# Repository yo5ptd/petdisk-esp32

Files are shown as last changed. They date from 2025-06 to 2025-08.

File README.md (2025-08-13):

# petdisk-esp32
CBM PETDISK based on Esp32 and MicroSD

## Introduction
My fourth PCB design, first (mostly) SMD one to test how ordering assembled PCB from JLCPCB works. Motivation for this was that it's a bit of a pain to order @bitfixer 's Petdisk Max V2 Esp32 from the US, and I've found no alternatives in the EU. 

## Hardware documentation

As per bitfixer's Petdisk V2 Max https://github.com/bitfixer/petdisk-max . Ports as per https://github.com/svenpetersen1965/PET-IEEE-488-Extension .

I've only changed the SD slot to Hanbo Electric TS-013 as this was available at JLCPCB.

### Schematic and PCB layout

[Schematic](CBM-Petdisk-Schematic.pdf)

[PCB Layout](CBM-Petdisk-Board.pdf)

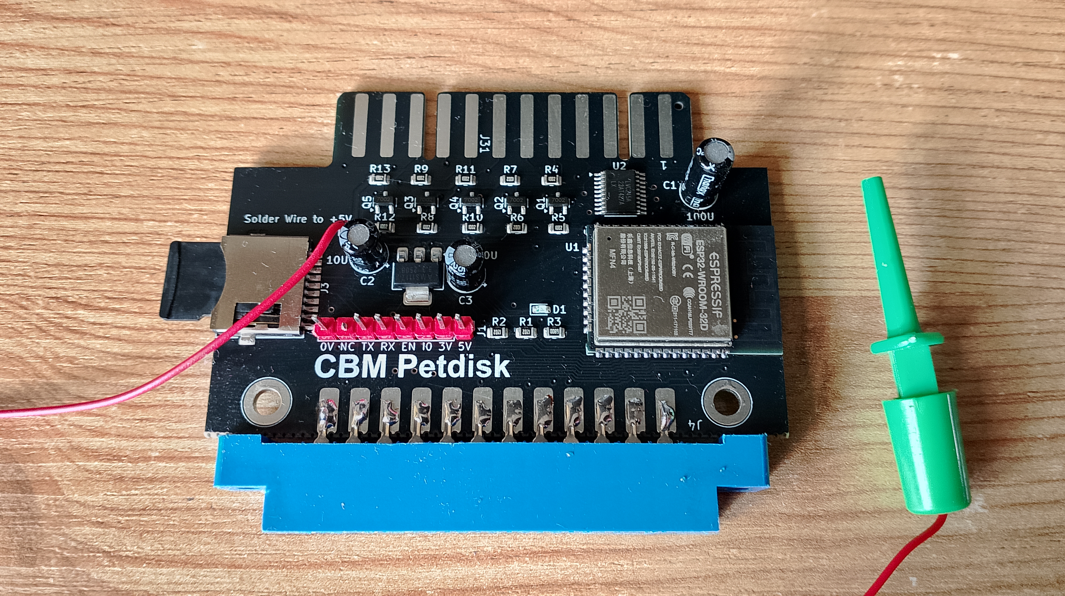
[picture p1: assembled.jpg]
Assembled


[Front](petdisk%20esp32.jpg)

[Back](petdisk%20esp32-back.jpg)

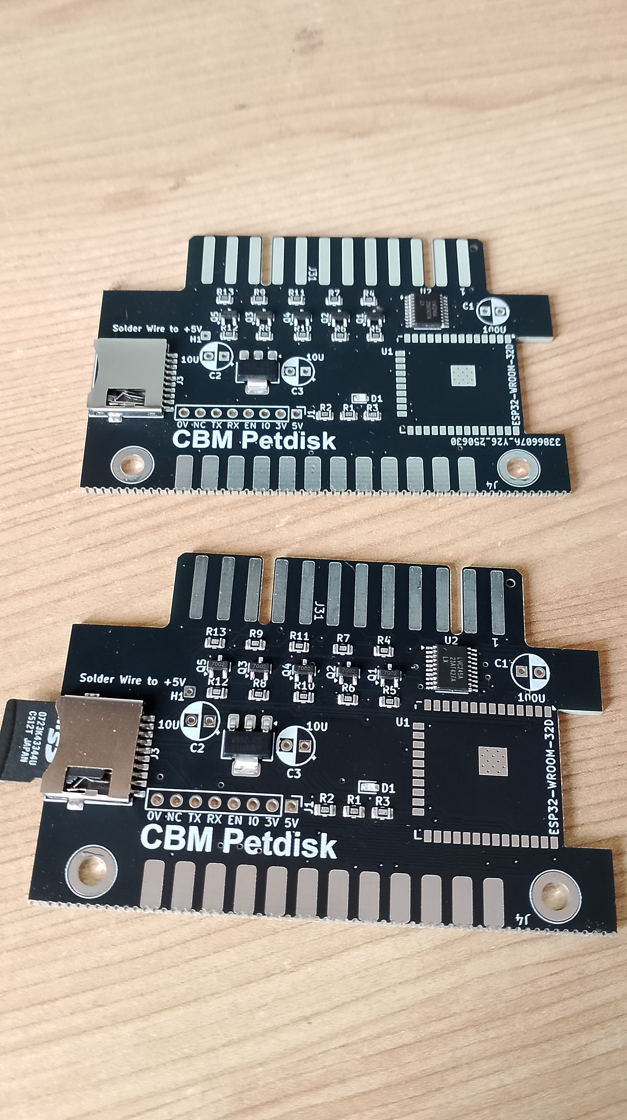
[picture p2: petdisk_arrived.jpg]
Received


## Panelization and odering from JLCPCB

Panelized with Kikit addon with hand-breakable "mousebytes", it still fits the 100x100 mm JLCPCB limit (Kikit.json settings included, details in https://github.com/yaqwsx/KiKit). 

The idea is to order the placement for the cheap SMD components, and only solder 3 electrolytic capacitors, the ESP32 module and a "805 Strip Connector 3.96mm Pitch 12 Pin" connector from Aliexpress. Cost per board from JLPCB thus is around 3.3$ when ordered in batches of 5 (10 boards in total, coupons used, shipping and taxes included) With connector, capacitors, esp32 should not get over 8.5$ per board, but probably more as I don't plan to order 10 of these.

You need the:
[Gerbers](gerbers.2xpetdisk-esp32.zip)

[BOM](BOM_JLCSMT.xlsx)

[CPL](JLCSMT_CPL.xlsx)

Disregards the duplicate message, also allow auto placement alignment.

## Programming

note that the programming port pinout is different from the original.

First board was fully assembled and tested on 29.07.2025. Note that I managed to get it working with the original Petdisk max v2.1 firmware with a 32GB card. 512mb, 1gb and 128gb cards were not recognized.

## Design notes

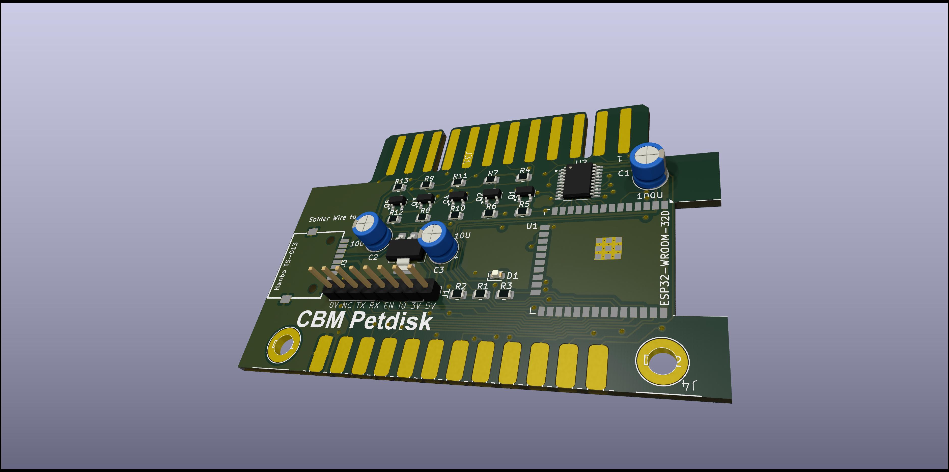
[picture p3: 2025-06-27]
petdisk esp32.jpg

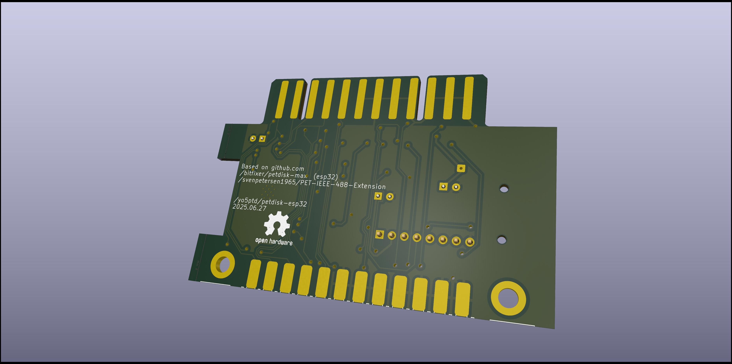
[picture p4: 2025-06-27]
petdisk esp32-back.jpg

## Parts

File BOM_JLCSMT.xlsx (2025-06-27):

Comment | Designator | Footprint | JLCPCB Part #（optional）
10K | R7,R8,R11,R12,R4,R9,R10,R5,R6,R13 | R_0805_2012Metric | C17414
BSS138K | Q1,Q3,Q2,Q5,Q4 | SOT-23 | C8545
Micro_SD_Card_Det2 | J3 | TF-SMD_TF-013 | C961683
LED | D1 | LED_0603_1608Metric | C2286
AMS1117-3.3 | U3 | SOT-223-3_TabPin2 | C6186
12K | R1,R2 | R_0805_2012Metric | C17444
1K | R3 | R_0805_2012Metric | C17798
SN74LVC245APW | U2 | TSSOP-20_4.4x6.5mm_P0.65mm | C41361216
ESP32-WROOM-32D | U1 | ESP32-WROOM-32D | C473012

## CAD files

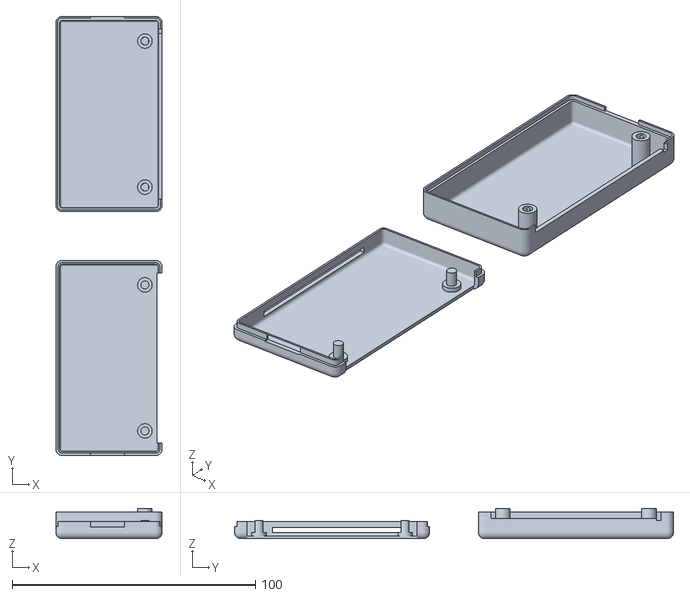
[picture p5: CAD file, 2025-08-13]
Yapp_petdisk_cbm.stl
43.7 x 180.4 x 12.4

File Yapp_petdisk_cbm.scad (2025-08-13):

/*
***************************************************************************  
**  Yet Another Parameterised Projectbox generator
**
*/

Version="v3.3.5 (2025-02-24)";

/*
**
**  Copyright (c) 2021, 2022, 2023, 2024, 2025 Willem Aandewiel
**
**  With help from:
**   - Keith Hadley (parameterized label depth)
**   - Oliver Grafe (connectorsPCB)
**   - Juan Jose Chong (dynamic standoff flange)
**   - Dan Drum (cleanup code)
**   - Dave Rosenhauer (fillets and a lot more)
**
**
**  for many or complex cutouts you might need to adjust
**  the number of elements:
**
**      Preferences->Advanced->Turn off rendering at 250000 elements
**                                                  ^^^^^^
**
**  TERMS OF USE: MIT License. See base offile.
***************************************************************************      
*/

// If set to true will generate the sample box at every save
debug = true;
printMessages = debug;

//---------------------------------------------------------
// This design is parameterized based on the size of a PCB.
//---------------------------------------------------------
// Note: length/lengte refers to X axis, 
//       width/breedte to Y, 
//       height/hoogte to Z

/*
      padding-back|<------pcb length --->|<padding-front
                            RIGHT
        0    X-axis ---> 
        +----------------------------------------+   ---
        |                                        |    ^
        |                                        |   padding-right 
      Y |                                        |    v
      | |    -5,y +----------------------+       |   ---              
 B    a |         | 0,y              x,y |       |     ^              F
 A    x |         |                      |       |     |              R
 C    i |         |                      |       |     | pcb width    O
 K    s |         |                      |       |     |              N
        |         | 0,0              x,0 |       |     v              T
      ^ |    -5,0 +----------------------+       |   ---
      | |                                        |    padding-left
      0 +----------------------------------------+   ---
        0    X-as --->
                          LEFT
*/

//-- which part(s) do you want to print?
printBaseShell        = true;
printLidShell         = true;
printSwitchExtenders  = true;
printDisplayClips     = true;
shiftLid              = 10;  // Set the distance between the lid and base when rendered or previewed side by side
                            
//-- padding between pcb and inside wall
paddingFront        = 1;
paddingBack         = 1;
paddingRight        = 1;
paddingLeft         = 1;

// ********************************************************************
// The Following will be used as the first element in the pbc array

//Defined here so you can define the "Main" PCB using these if wanted
pcbLength           = 38.5; // front to back (X axis)
pcbWidth            = 75; // side to side (Y axis)
pcbThickness        = 1.6;
standoffHeight      = 1.5;  //-- How much the PCB needs to be raised from the base to leave room for solderings 
standoffDiameter    = 6;
standoffPinDiameter = 3.3;
standoffHoleSlack   = 0.4;

//===================================================================
// *** PCBs ***
// Printed Circuit Boards
//-------------------------------------------------------------------
//  Default origin =  yappCoordPCB : yappCoordBoxInside[0,0,0]
//
//  Parameters:
//   Required:
//    p(0) = name
//    p(1) = length
//    p(2) = width
//    p(3) = posx
//    p(4) = posy
//    p(5) = Thickness
//    p(6) = standoff_Height = Height to bottom of PCB from the inside of the base
//             negative measures from inside of the lid to the top of the PCB
//    p(7) = standoff_Diameter
//    p(8) = standoff_PinDiameter
//   Optional:
//    p(9) = standoff_HoleSlack (default to 0.4)

//The following can be used to get PCB values. If "PCB Name" is omitted then "Main" is used
//  pcbLength           --> pcbLength("PCB Name")
//  pcbWidth            --> pcbWidth("PCB Name")
//  pcbThickness        --> pcbThickness("PCB Name") 
//  standoffHeight      --> standoffHeight("PCB Name") 
//  standoffDiameter    --> standoffDiameter("PCB Name") 
//  standoffPinDiameter --> standoffPinDiameter("PCB Name") 
//  standoffHoleSlack   --> standoffHoleSlack("PCB Name") 

pcb = 
[
  //-- Default Main PCB - DO NOT REMOVE the "Main" line.
  ["Main",              pcbLength,pcbWidth,    0,0,    pcbThickness,  standoffHeight, standoffDiameter, standoffPinDiameter, standoffHoleSlack]
];

//-------------------------------------------------------------------

//-- Edit these parameters for your own box dimensions
wallThickness       = 1.6;
basePlaneThickness  = 1.0;
lidPlaneThickness   = 1.0;

//-- Total height of box = lidPlaneThickness 
//                       + lidWallHeight 
//                       + baseWallHeight 
//                       + basePlaneThickness
//-- space between pcb and lidPlane :=
//--      (bottonWallHeight+lidWallHeight) - (standoff_Height+pcb_Thickness)
baseWallHeight      = 6;
lidWallHeight       = 8.5;

//-- ridge where base and lid off box can overlap
//-- Make sure this isn't less than lidWallHeight 
//     or 1.8x wallThickness if using snaps
ridgeHeight         = 2.0;
ridgeSlack          = 0.3;

//-- Radius of the shell corners
roundRadius         = wallThickness + 1;

// Box Types are 0-5 with 0 as the default
// 0 = All edges rounded with radius (roundRadius) above
// 1 = All edges square
// 2 = All edges chamfered by (roundRadius) above 
// 3 = Square top and bottom edges (the ones that touch the build plate) and rounded vertical edges
// 4 = Square top and bottom edges (the ones that touch the build plate) and chamfered vertical edges
// 5 = Chamfered top and bottom edges (the ones that touch the build plate) and rounded vertical edges
boxType = 0; // Default type 0


//---------------------------
//--     MISC Options     --
//---------------------------

//-- Cone aperture in degrees for countersunk-head screws
countersinkAngle = 90;          //-- metric: 90

// Set the layer height of your printer
printerLayerHeight  = 0.2;

// Set the ratio between the wall thickness and the ridge height. 
//    Recommended to be left at 1.8 but for strong snaps.
wallToRidgeRatio = 1.8;

//---------------------------
//--     C O N T R O L     --
//---------------------------
// -- Render --
renderQuality             = 8;          //-> from 1 to 32, Default = 8

// --Preview --
previewQuality            = 5;          //-> from 1 to 32, Default = 5
showSideBySide            = true;       //-> Default = true
onLidGap                  = 0;  // tip don't override to animate the lid opening
//onLidGap                  = ((ridgeHeight) - (ridgeHeight * abs(($t-0.5)*2)))*2;  // tip don't override to animate the lid opening/closing
colorLid                  = "YellowGreen";   
alphaLid                  = 1;
colorBase                 = "BurlyWood";
alphaBase                 = 1;
hideLidWalls              = false;      //-> Remove the walls from the lid : only if preview and showSideBySide=true 
hideBaseWalls             = false;      //-> Remove the walls from the base : only if preview and showSideBySide=true  
showOrientation           = true;       //-> Show the Front/Back/Left/Right labels : only in preview
showPCB                   = false;      //-> Show the PCB in red : only in preview 
showSwitches              = false;      //-> Show the switches (for pushbuttons) : only in preview 
showButtonsDepressed      = false;      //-> Should the buttons in the Lid On view be in the pressed position
showOriginCoordBox        = false;      //-> Shows red bars representing the origin for yappCoordBox : only in preview 
showOriginCoordBoxInside  = false;      //-> Shows blue bars representing the origin for yappCoordBoxInside : only in preview 
showOriginCoordPCB        = false;      //-> Shows blue bars representing the origin for yappCoordBoxInside : only in preview 
showMarkersPCB            = false;      //-> Shows black bars corners of the PCB : only in preview 
showMarkersCenter         = false;      //-> Shows magenta bars along the centers of all faces  
inspectX                  = 0;          //-> 0=none (>0 from Back)
inspectY                  = 0;          //-> 0=none (>0 from Right)
inspectZ                  = 0;          //-> 0=none (>0 from Bottom)
inspectXfromBack          = true;       //-> View from the inspection cut foreward
inspectYfromLeft          = true;       //-> View from the inspection cut to the right
inspectZfromBottom        = true;       //-> View from the inspection cut up
//---------------------------
//--     C O N T R O L     --
//---------------------------

// ******************************
//  REMOVE BELOW FROM TEMPLATE

// Set the glogal for the quality
facetCount = $preview ? previewQuality*4 : renderQuality*4;
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

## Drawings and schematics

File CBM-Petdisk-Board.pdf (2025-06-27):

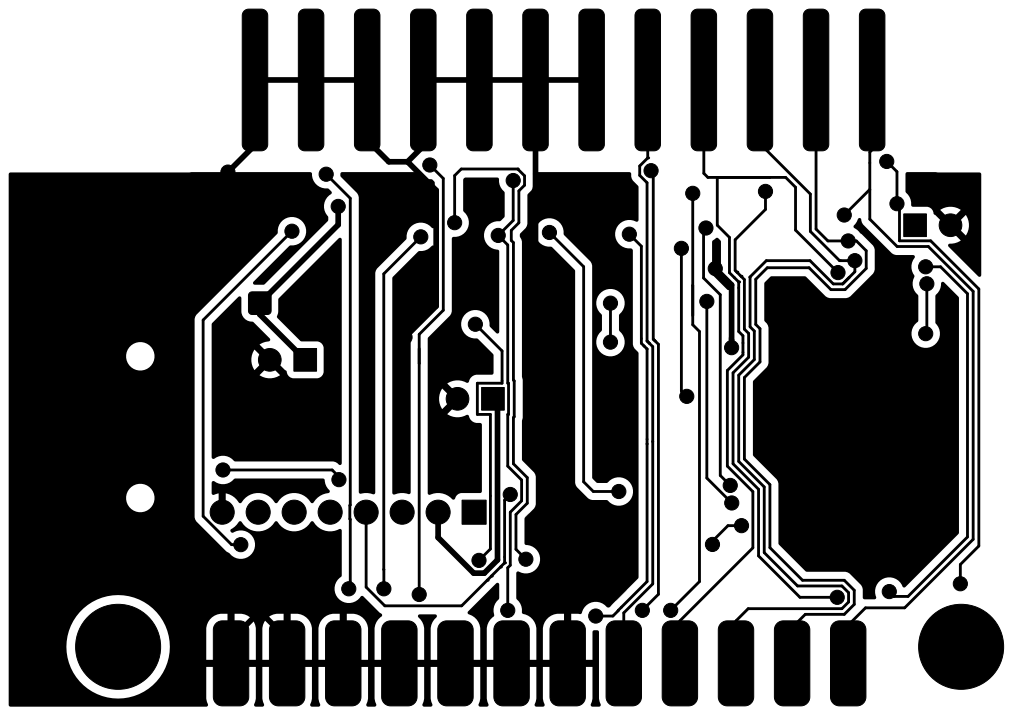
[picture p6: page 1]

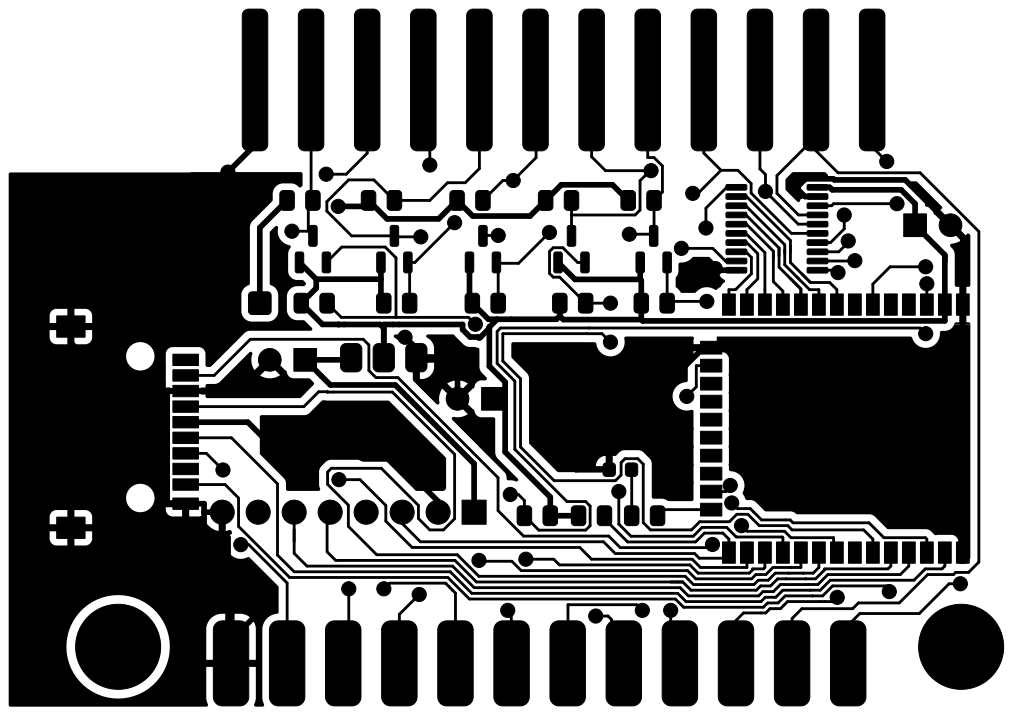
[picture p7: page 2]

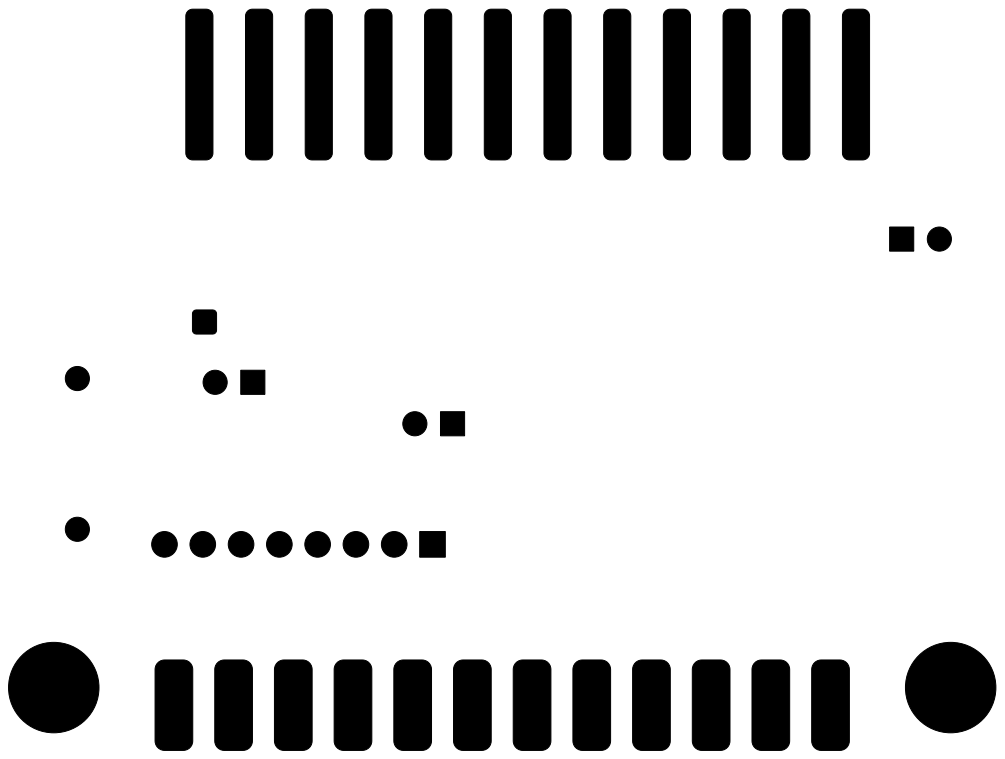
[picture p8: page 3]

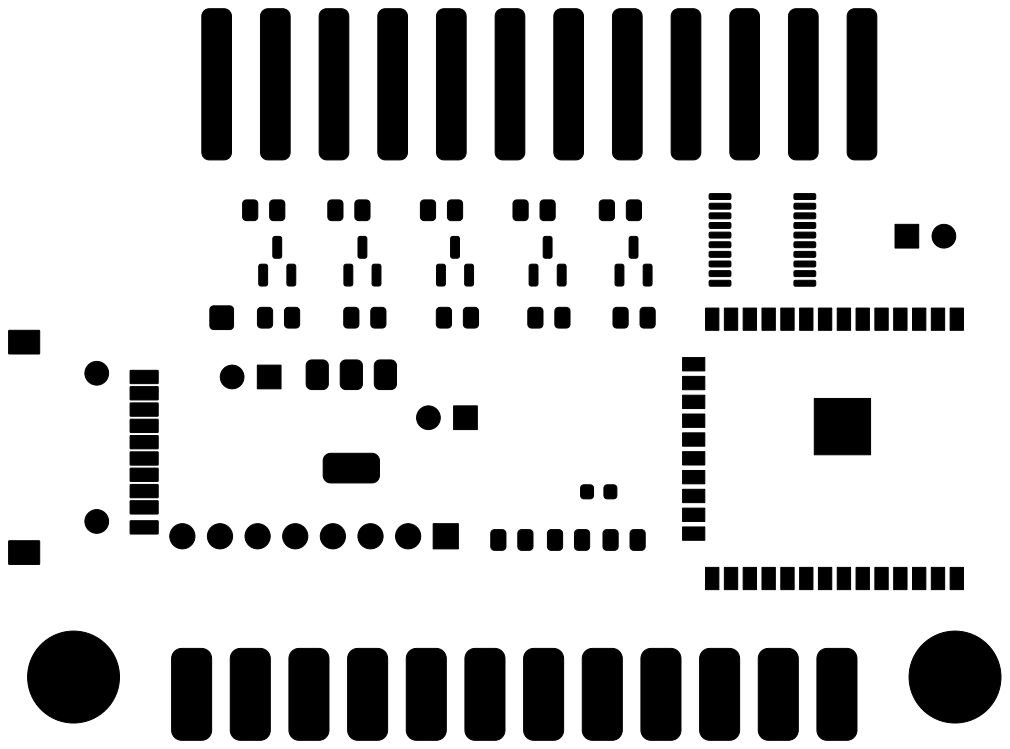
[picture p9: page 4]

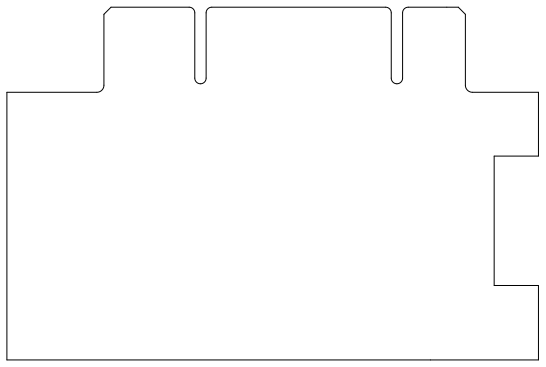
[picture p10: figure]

U2 10K R13 | BOHR3,5 Conn_01x08 | J1 BOHR3,5

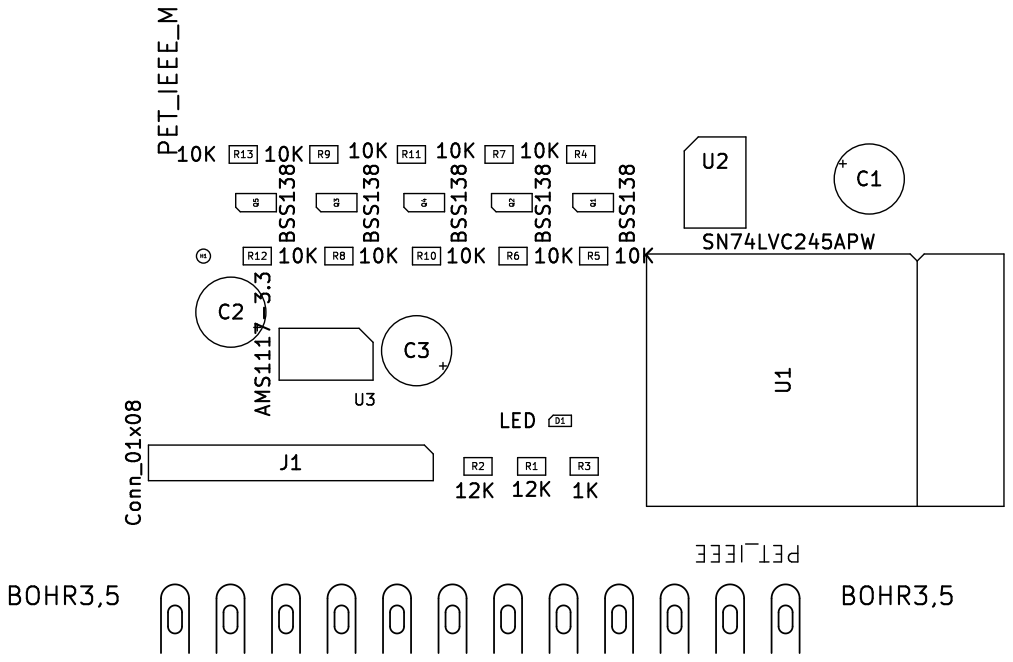
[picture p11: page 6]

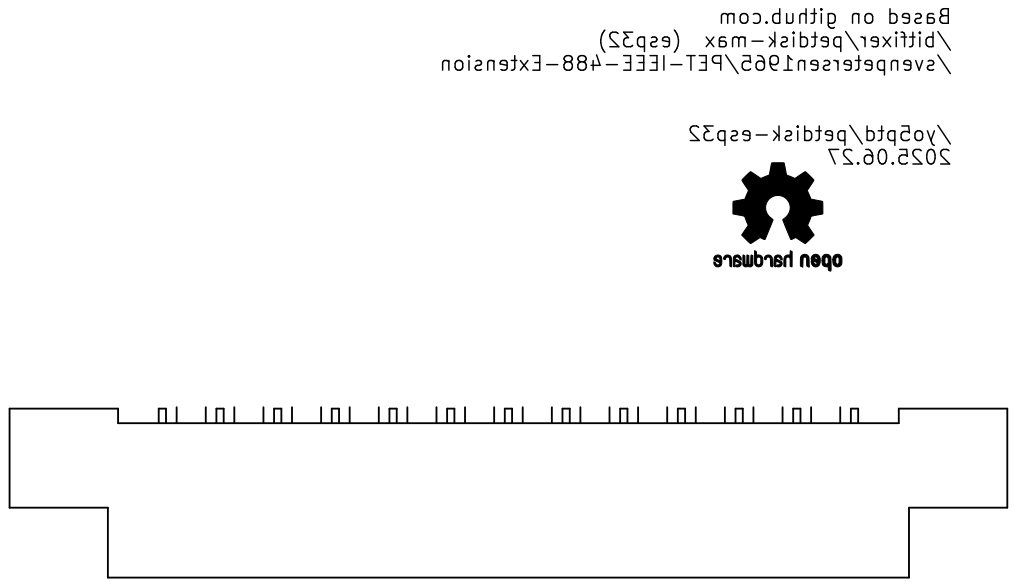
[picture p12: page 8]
/yo5ptd/petdisk-esp32 2025.06.27

github.com on Based

/svenpetersen1965/PET-IEEE-488-Extension

(esp32) /bitfixer/petdisk-max

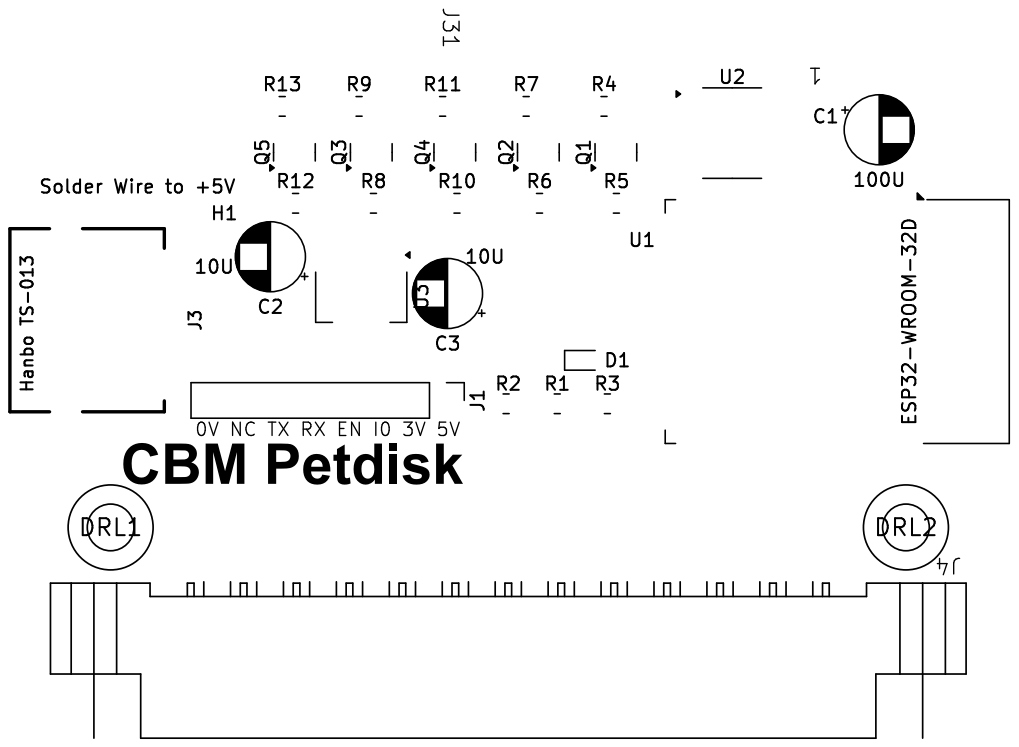
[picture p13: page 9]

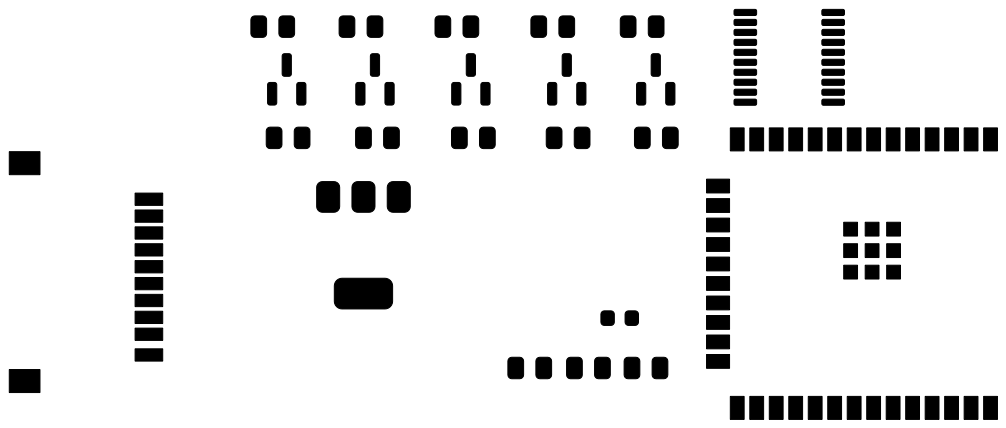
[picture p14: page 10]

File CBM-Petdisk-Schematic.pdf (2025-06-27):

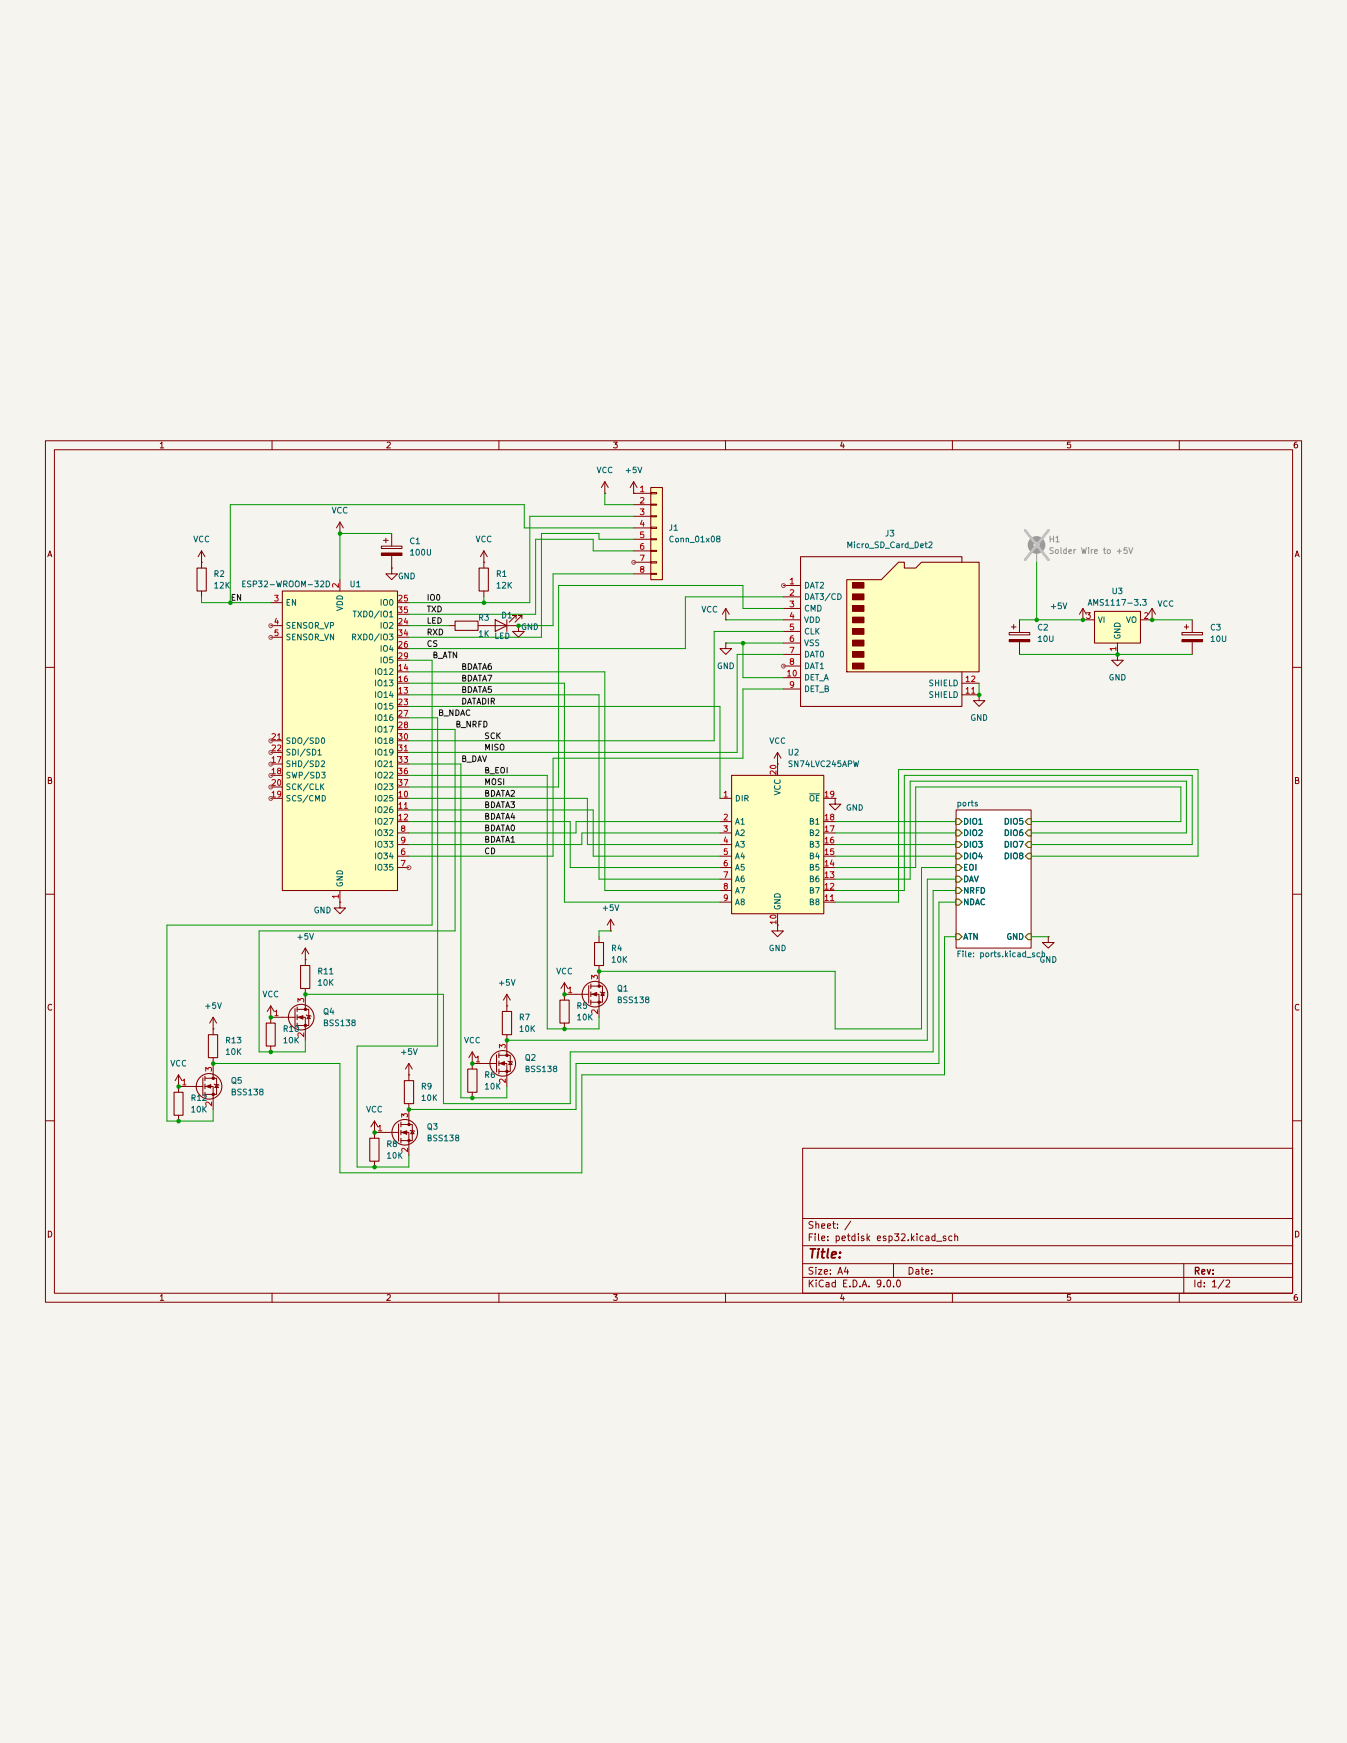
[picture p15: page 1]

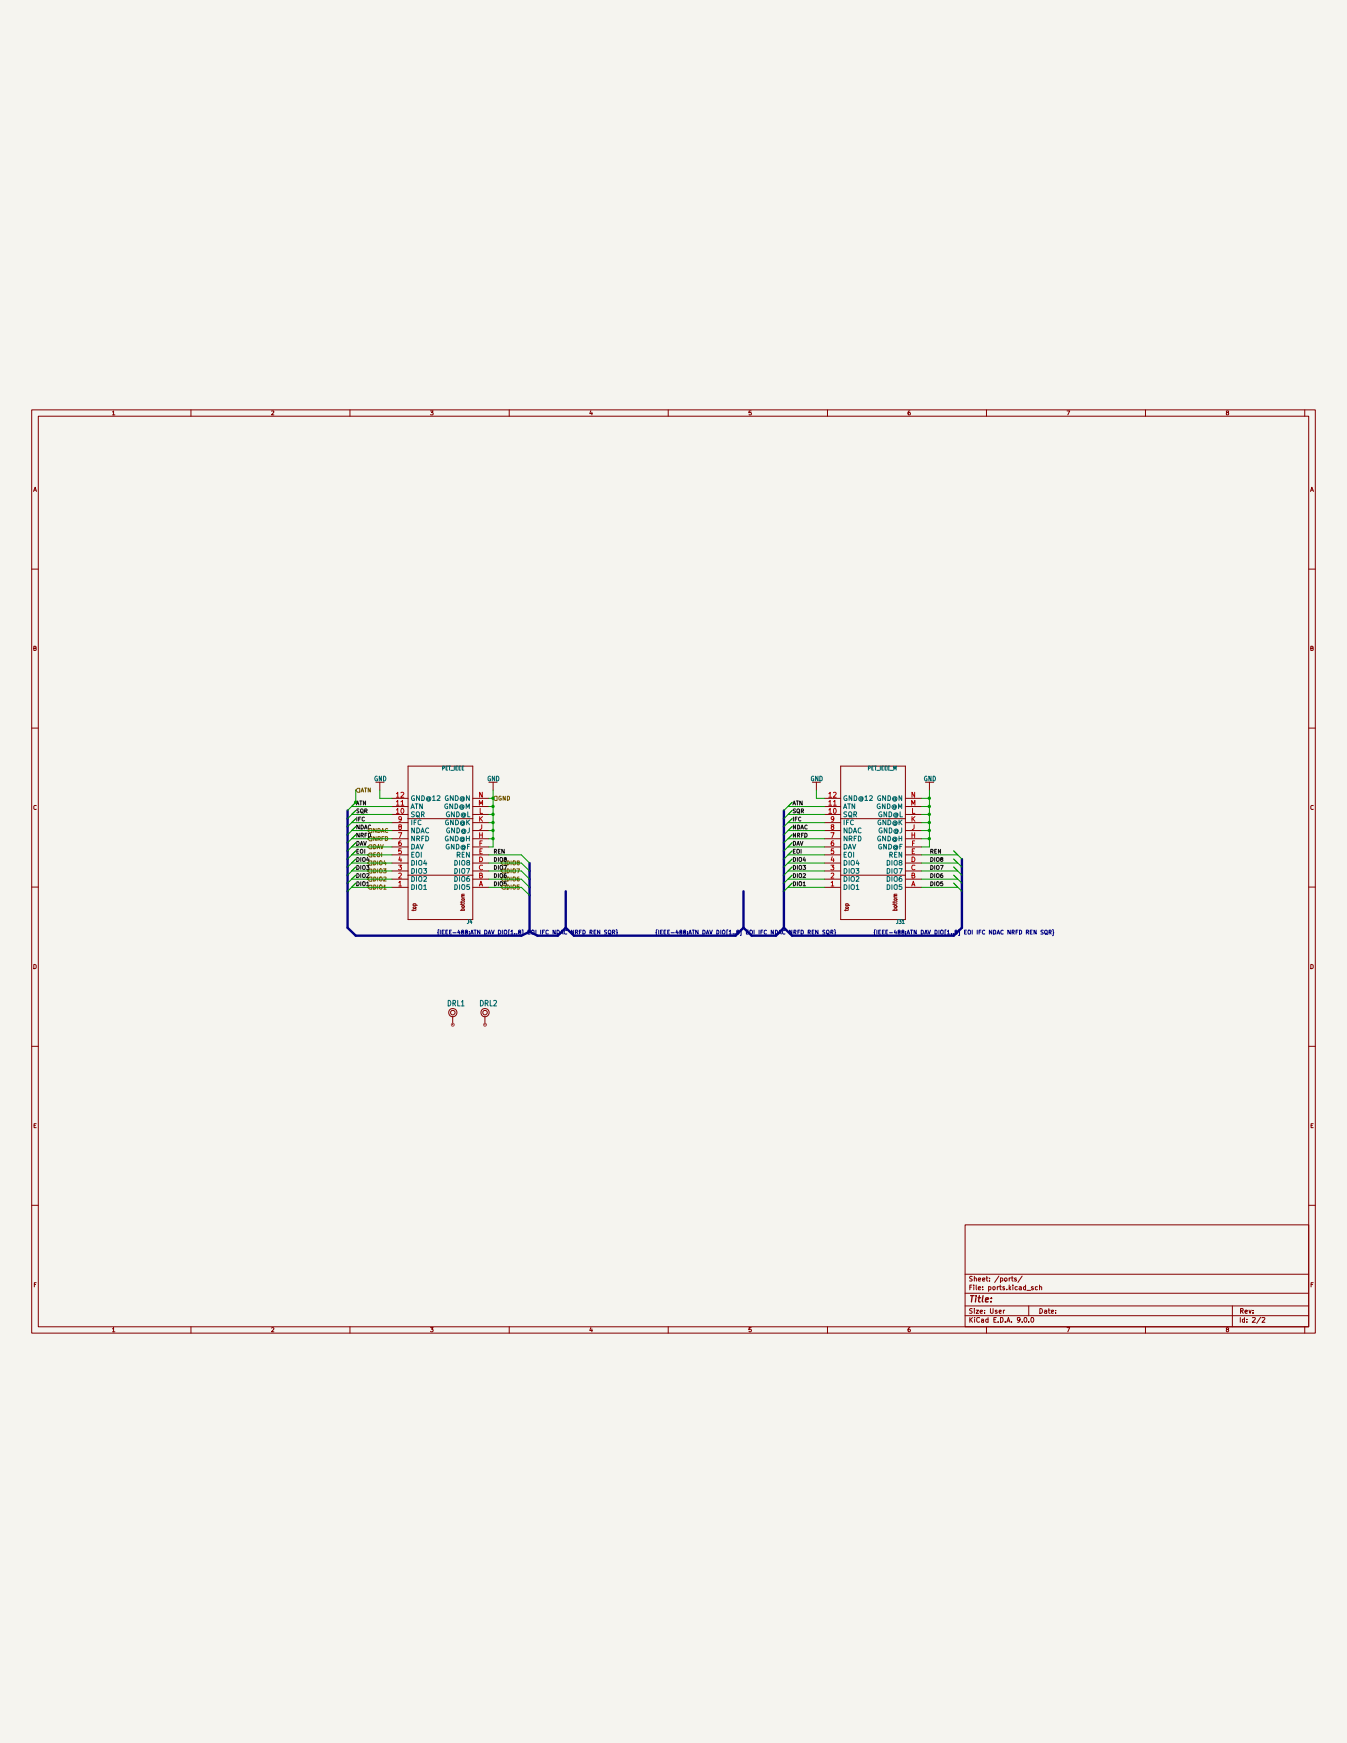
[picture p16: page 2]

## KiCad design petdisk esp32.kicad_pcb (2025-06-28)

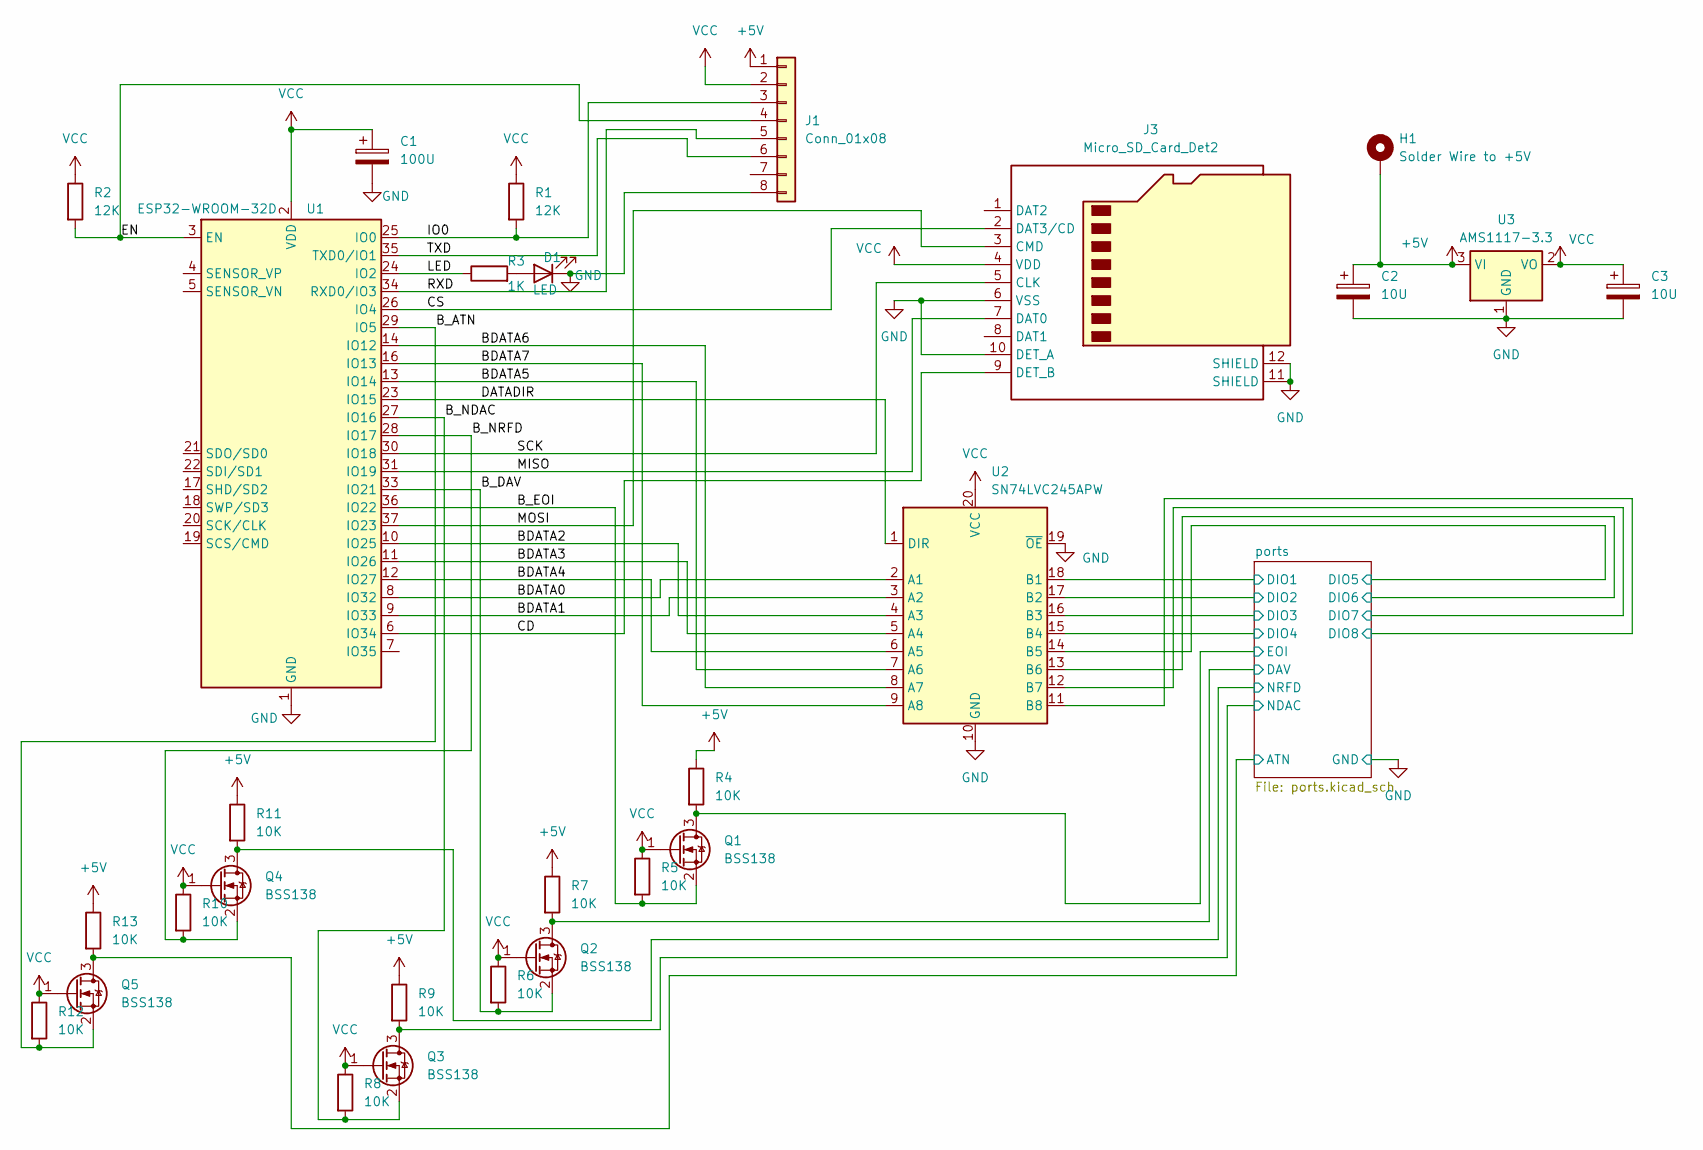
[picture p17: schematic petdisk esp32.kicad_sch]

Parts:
C1: 100U; CP_Radial_D5.0mm_P2.50mm
C2, C3: 10U; CP_Radial_D5.0mm_P2.50mm
D1: LED; LED_0603_1608Metric
H1: Solder Wire to +5V; SolderWire-0.1sqmm_1x01_D0.4mm_OD1mm
J1: Conn_01x08; PinHeader_1x08_P2.54mm_Vertical
J3: Micro_SD_Card_Det2; TF-SMD_TF-013
Q1, Q2, Q3, Q4, Q5: BSS138; SOT-23
R1, R2: 12K; R_0805_2012Metric
R3: 1K; R_0805_2012Metric
R4, R5, R6, R7, R8, R9, R10, R11, R12, R13: 10K; R_0805_2012Metric
U1: ESP32-WROOM-32D
U2: SN74LVC245APW; TSSOP-20_4.4x6.5mm_P0.65mm
U3: AMS1117-3.3; SOT-223-3_TabPin2

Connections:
+5V: C2.1, H1.1, J1.1, R4.1, R7.1, R9.1, R11.1, R13.1, U3.3 (VI)
/BDATA0: U1.8 (IO32), U2.2 (A1)
/BDATA1: U1.9 (IO33), U2.3 (A2)
/BDATA2: U1.10 (IO25), U2.4 (A3)
/BDATA3: U1.11 (IO26), U2.5 (A4)
/BDATA4: U1.12 (IO27), U2.6 (A5)
/BDATA5: U1.13 (IO14), U2.7 (A6)
/BDATA6: U1.14 (IO12), U2.8 (A7)
/BDATA7: U1.16 (IO13), U2.9 (A8)
/B_ATN: Q5.2 (S), R12.2, U1.29 (IO5)
/B_DAV: Q2.2 (S), R6.2, U1.33 (IO21)
/B_EOI: Q1.2 (S), R5.2, U1.36 (IO22)
/B_NDAC: Q3.2 (S), R8.2, U1.27 (IO16)
/B_NRFD: Q4.2 (S), R10.2, U1.28 (IO17)
/CD: J3.9 (DET_B), U1.6 (IO34)
/CS: J3.2 (DAT3/CD), U1.26 (IO4)
/DATADIR: U1.23 (IO15), U2.1 (DIR)
/EN: J1.4, R2.2, U1.3 (EN)
/IO0: J1.3, R1.2, U1.25 (IO0)
/LED: R3.1, U1.24 (IO2)
/MISO: J3.7 (DAT0), U1.31 (IO19)
/MOSI: J3.3 (CMD), U1.37 (IO23)
/RXD: J1.5, U1.34 (RXD0/IO3)
/SCK: J3.5 (CLK), U1.30 (IO18)
/TXD: J1.6, U1.35 (TXD0/IO1)
/ports/ATN: Q5.3 (D), R13.2; also elsewhere on the board
/ports/DAV: Q2.3 (D), R7.2; also elsewhere on the board
/ports/DIO1: U2.18 (B1); also elsewhere on the board
/ports/DIO2: U2.17 (B2); also elsewhere on the board
/ports/DIO3: U2.16 (B3); also elsewhere on the board
/ports/DIO4: U2.15 (B4); also elsewhere on the board
/ports/DIO5: U2.14 (B5); also elsewhere on the board
/ports/DIO6: U2.13 (B6); also elsewhere on the board
/ports/DIO7: U2.12 (B7); also elsewhere on the board
/ports/DIO8: U2.11 (B8); also elsewhere on the board
/ports/EOI: Q1.3 (D), R4.2; also elsewhere on the board
/ports/NDAC: Q3.3 (D), R9.2; also elsewhere on the board
/ports/NRFD: Q4.3 (D), R11.2; also elsewhere on the board
GND: C1.2, C2.2, C3.2, D1.1 (K), J1.8, J3.6 (VSS), J3.10 (DET_A), J3.11 (SHIELD), J3.12 (SHIELD), U1.1 (GND), U1.15 (GND), U1.38 (GND), U1.39 (GND), U2.10 (GND), U2.19 (~OE), U3.1 (GND); also elsewhere on the board
unnamed: D1.2 (A), R3.2
VCC: C1.1, C3.1, J1.2, J3.4 (VDD), Q1.1 (G), Q2.1 (G), Q3.1 (G), Q4.1 (G), Q5.1 (G), R1.1, R2.1, R5.1, R6.1, R8.1, R10.1, R12.1, U1.2 (VDD), U2.20 (VCC), U3.2 (VO)

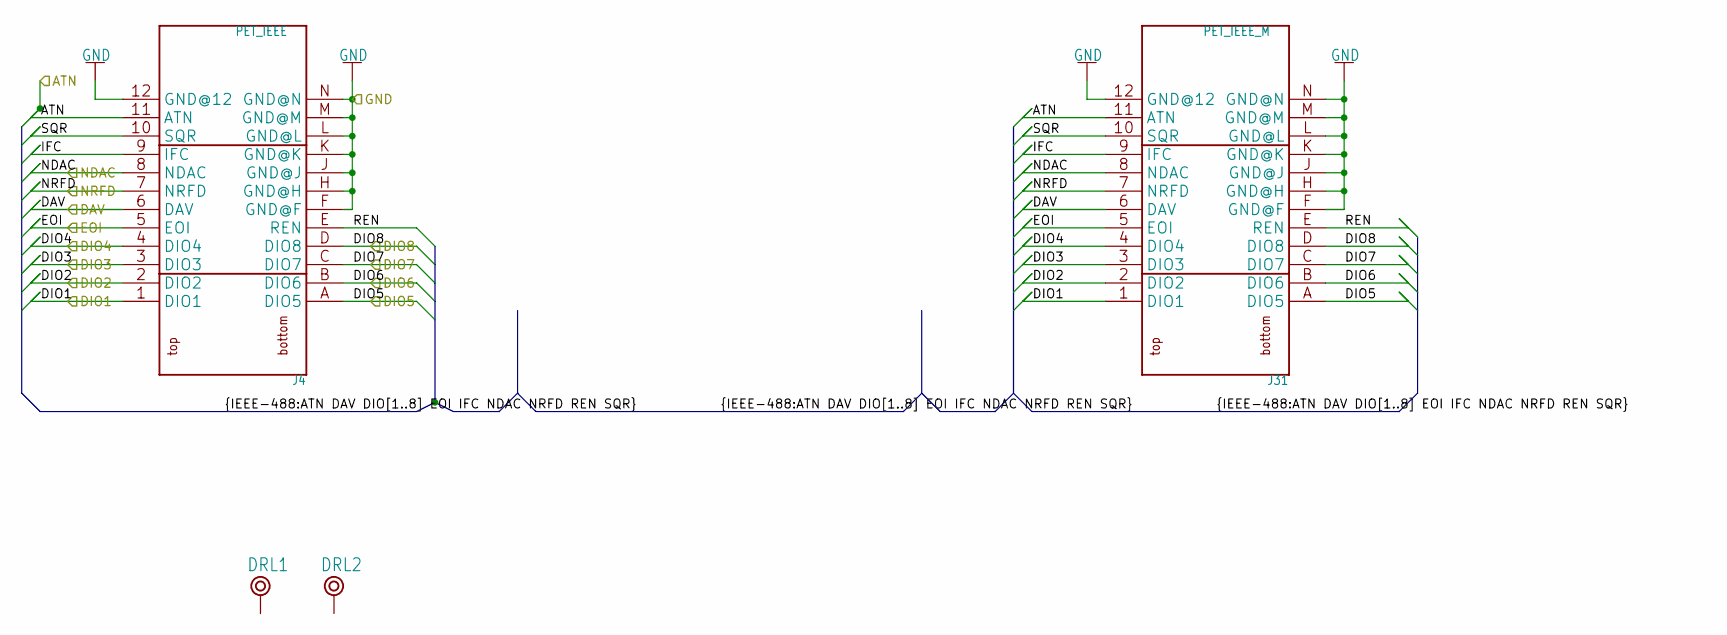
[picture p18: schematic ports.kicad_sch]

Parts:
DRL1, DRL2: BOHR3,5
J4: PET_IEEE; USERPORT
J31: PET_IEEE_M

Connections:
/ports/ATN: J4.11 (ATN), J31.11 (ATN); also elsewhere on the board
/ports/DAV: J4.6 (DAV), J31.6 (DAV); also elsewhere on the board
/ports/DIO1: J4.1 (DIO1), J31.1 (DIO1); also elsewhere on the board
/ports/DIO2: J4.2 (DIO2), J31.2 (DIO2); also elsewhere on the board
/ports/DIO3: J4.3 (DIO3), J31.3 (DIO3); also elsewhere on the board
/ports/DIO4: J4.4 (DIO4), J31.4 (DIO4); also elsewhere on the board
/ports/DIO5: J4.A (DIO5), J31.A (DIO5); also elsewhere on the board
/ports/DIO6: J4.B (DIO6), J31.B (DIO6); also elsewhere on the board
/ports/DIO7: J4.C (DIO7), J31.C (DIO7); also elsewhere on the board
/ports/DIO8: J4.D (DIO8), J31.D (DIO8); also elsewhere on the board
/ports/EOI: J4.5 (EOI), J31.5 (EOI); also elsewhere on the board
/ports/IFC: J4.9 (IFC), J31.9 (IFC)
/ports/NDAC: J4.8 (NDAC), J31.8 (NDAC); also elsewhere on the board
/ports/NRFD: J4.7 (NRFD), J31.7 (NRFD); also elsewhere on the board
/ports/REN: J4.E (REN), J31.E (REN)
/ports/SQR: J4.10 (SQR), J31.10 (SQR)
GND: J4.12 (GND@12), J4.F (GND@F), J4.H (GND@H), J4.J (GND@J), J4.K (GND@K), J4.L (GND@L), J4.M (GND@M), J4.N (GND@N), J31.12 (GND@12), J31.F (GND@F), J31.H (GND@H), J31.J (GND@J), J31.K (GND@K), J31.L (GND@L), J31.M (GND@M), J31.N (GND@N); also elsewhere on the board

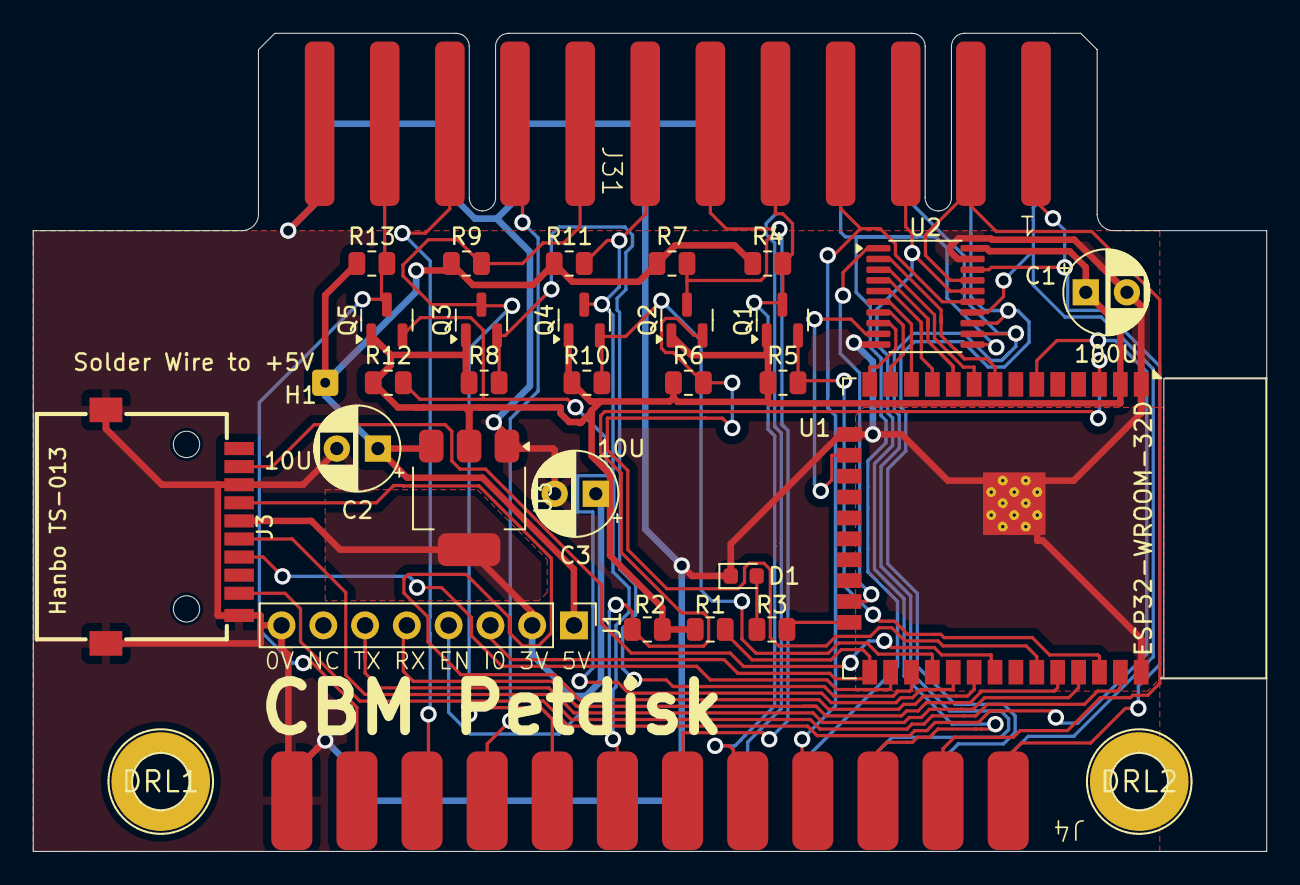
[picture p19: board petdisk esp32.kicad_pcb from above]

Board: 2 copper layers, 75.0 x 49.8 mm, 32 parts (0 on the bottom side), 44 nets.

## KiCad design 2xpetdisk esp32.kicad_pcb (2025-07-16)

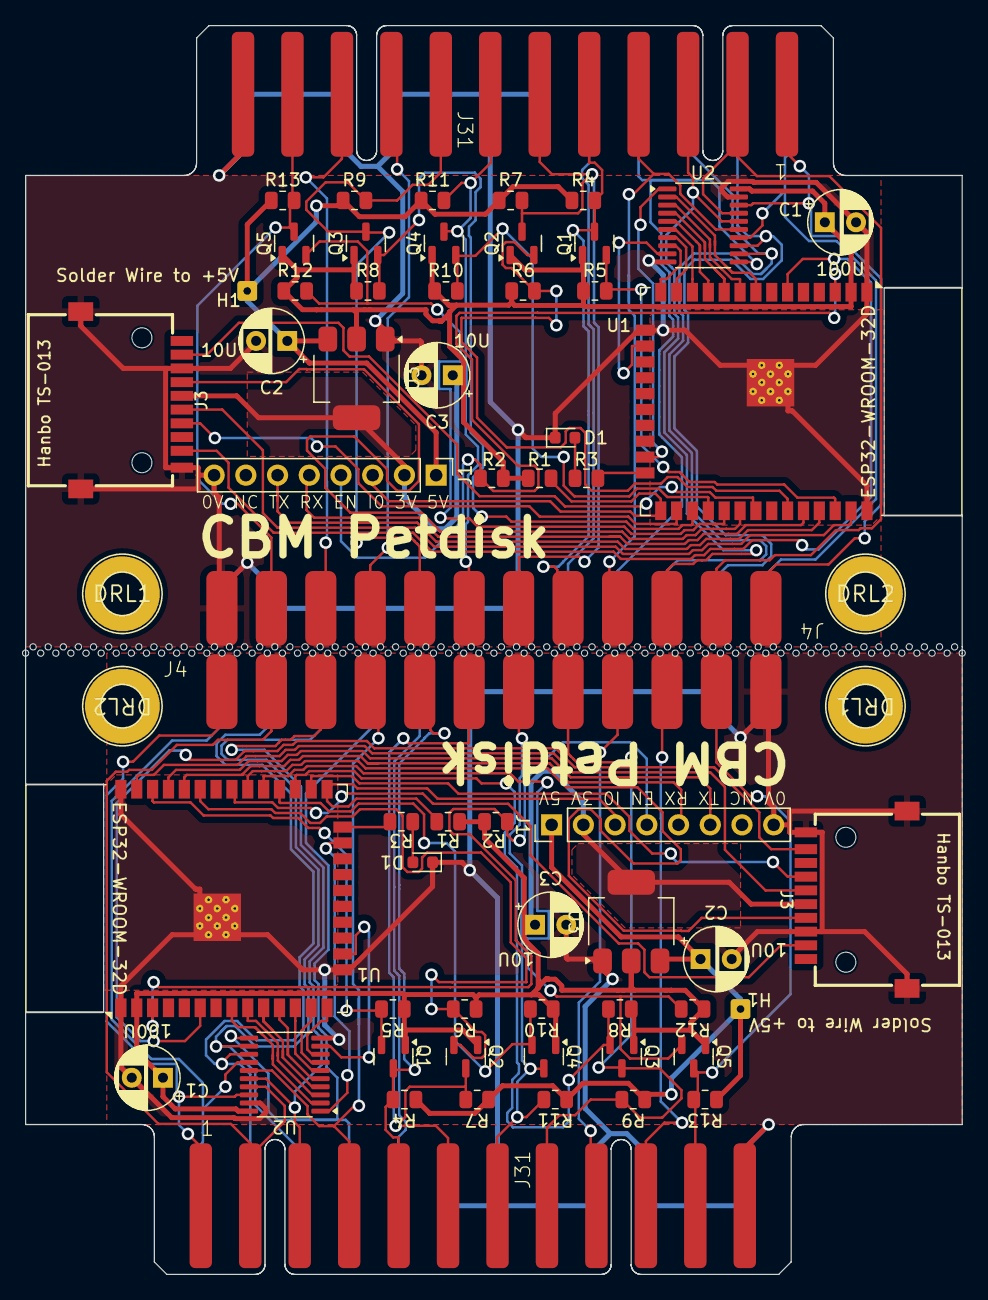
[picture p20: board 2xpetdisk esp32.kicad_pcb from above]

Board: 2 copper layers, 75.0 x 100.0 mm, 189 parts (0 on the bottom side), 88 nets.

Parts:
C1, C1#2: 100U; CP_Radial_D5.0mm_P2.50mm
C2, C2#2, C3, C3#2: 10U; CP_Radial_D5.0mm_P2.50mm
D1, D1#2: LED; LED_0603_1608Metric
DRL1, DRL1#2, DRL2, DRL2#2: BOHR3,5
H1, H1#2: Solder Wire to +5V; SolderWire-0.1sqmm_1x01_D0.4mm_OD1mm
J1, J1#2: Conn_01x08; PinHeader_1x08_P2.54mm_Vertical
J3, J3#2: Hanbo TS-013; TF-SMD_TF-013
J4, J4#2: PET_IEEE; USERPORT
J31, J31#2: PET_IEEE_M
KiKit_MB_1_2, KiKit_MB_1_3, KiKit_MB_1_4, KiKit_MB_1_5, KiKit_MB_1_6, KiKit_MB_1_7, KiKit_MB_1_8, KiKit_MB_1_9, KiKit_MB_1_10, KiKit_MB_1_11, KiKit_MB_1_12, KiKit_MB_1_13, KiKit_MB_1_14, KiKit_MB_1_15, KiKit_MB_1_16, KiKit_MB_1_17, KiKit_MB_1_18, KiKit_MB_1_19, KiKit_MB_1_20, KiKit_MB_1_21, KiKit_MB_1_22, KiKit_MB_1_23, KiKit_MB_1_24, KiKit_MB_1_25, KiKit_MB_1_26, KiKit_MB_1_27, KiKit_MB_1_28, KiKit_MB_1_29, KiKit_MB_1_30, KiKit_MB_1_31, KiKit_MB_1_32, KiKit_MB_1_33, KiKit_MB_1_34, KiKit_MB_1_35, KiKit_MB_1_36, KiKit_MB_1_37, KiKit_MB_1_38, KiKit_MB_1_39, KiKit_MB_1_40, KiKit_MB_1_41, KiKit_MB_1_42, KiKit_MB_1_43, KiKit_MB_1_44, KiKit_MB_1_45, KiKit_MB_1_46, KiKit_MB_1_47, KiKit_MB_1_48, KiKit_MB_1_49, KiKit_MB_1_50, KiKit_MB_1_51, KiKit_MB_1_52, KiKit_MB_1_53, KiKit_MB_1_54, KiKit_MB_1_55, KiKit_MB_1_56, KiKit_MB_1_57, KiKit_MB_1_58, KiKit_MB_1_59, KiKit_MB_1_60, KiKit_MB_1_61, KiKit_MB_1_62, KiKit_MB_1_63, KiKit_MB_2_1, KiKit_MB_2_2, KiKit_MB_2_3, KiKit_MB_2_4, KiKit_MB_2_5, KiKit_MB_2_6, KiKit_MB_2_7, KiKit_MB_2_8, KiKit_MB_2_9, KiKit_MB_2_10, KiKit_MB_2_11, KiKit_MB_2_12, KiKit_MB_2_13, KiKit_MB_2_14, KiKit_MB_2_15, KiKit_MB_2_16, KiKit_MB_2_17, KiKit_MB_2_18, KiKit_MB_2_19, KiKit_MB_2_20, KiKit_MB_2_21, KiKit_MB_2_22, KiKit_MB_2_23, KiKit_MB_2_24, KiKit_MB_2_25, KiKit_MB_2_26, KiKit_MB_2_27, KiKit_MB_2_28, KiKit_MB_2_29, KiKit_MB_2_30, KiKit_MB_2_31, KiKit_MB_2_32, KiKit_MB_2_33, KiKit_MB_2_34, KiKit_MB_2_35, KiKit_MB_2_36, KiKit_MB_2_37, KiKit_MB_2_38, KiKit_MB_2_39, KiKit_MB_2_40, KiKit_MB_2_41, KiKit_MB_2_42, KiKit_MB_2_43, KiKit_MB_2_44, KiKit_MB_2_45, KiKit_MB_2_46, KiKit_MB_2_47, KiKit_MB_2_48, KiKit_MB_2_49, KiKit_MB_2_50, KiKit_MB_2_51, KiKit_MB_2_52, KiKit_MB_2_53, KiKit_MB_2_54, KiKit_MB_2_55, KiKit_MB_2_56, KiKit_MB_2_57, KiKit_MB_2_58, KiKit_MB_2_59, KiKit_MB_2_60, KiKit_MB_2_61, KiKit_MB_2_62, KiKit_MB_2_63: NPTH
Q1, Q1#2, Q2, Q2#2, Q3, Q3#2, Q4, Q4#2, Q5, Q5#2: BSS138; SOT-23
R1, R1#2, R2, R2#2: 12K; R_0805_2012Metric
R3, R3#2: 1K; R_0805_2012Metric
R4, R4#2, R5, R5#2, R6, R6#2, R7, R7#2, R8, R8#2, R9, R9#2, R10, R10#2, R11, R11#2, R12, R12#2, R13, R13#2: 10K; R_0805_2012Metric
U1, U1#2: ESP32-WROOM-32D
U2, U2#2: SN74LVC245APW; TSSOP-20_4.4x6.5mm_P0.65mm
U3, U3#2: AMS1117-3.3; SOT-223-3_TabPin2

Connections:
Board_0-+5V: C2.1, H1.1, J1.1, R4#2.1, R7.1, R9.1, R11#2.1, R13#2.1, U3#2.3 (VI)
Board_0-/BDATA0: U1#2.8 (IO32), U2#2.2 (A1)
Board_0-/BDATA1: U1#2.9 (IO33), U2#2.3 (A2)
Board_0-/BDATA2: U1#2.10 (IO25), U2#2.4 (A3)
Board_0-/BDATA3: U1#2.11 (IO26), U2#2.5 (A4)
Board_0-/BDATA4: U1#2.12 (IO27), U2#2.6 (A5)
Board_0-/BDATA5: U1#2.13 (IO14), U2#2.7 (A6)
Board_0-/BDATA6: U1#2.14 (IO12), U2#2.8 (A7)
Board_0-/BDATA7: U1#2.16 (IO13), U2#2.9 (A8)
Board_0-/B_ATN: Q5.2 (S), R12.2, U1#2.29 (IO5)
Board_0-/B_DAV: Q2.2 (S), R6#2.2, U1#2.33 (IO21)
Board_0-/B_EOI: Q1#2.2 (S), R5#2.2, U1#2.36 (IO22)
Board_0-/B_NDAC: Q3.2 (S), R8#2.2, U1#2.27 (IO16)
Board_0-/B_NRFD: Q4.2 (S), R10#2.2, U1#2.28 (IO17)
Board_0-/CD: J3.9 (DET_B), U1#2.6 (IO34)
Board_0-/CS: J3.2 (DAT3/CD), U1#2.26 (IO4)
Board_0-/DATADIR: U1#2.23 (IO15), U2#2.1 (DIR)
Board_0-/EN: J1.4, R2.2, U1#2.3 (EN)
Board_0-/IO0: J1.3, R1.2, U1#2.25 (IO0)
Board_0-/LED: R3.1, U1#2.24 (IO2)
Board_0-/MISO: J3.7 (DAT0), U1#2.31 (IO19)
Board_0-/MOSI: J3.3 (CMD), U1#2.37 (IO23)
Board_0-/RXD: J1.5, U1#2.34 (RXD0/IO3)
Board_0-/SCK: J3.5 (CLK), U1#2.30 (IO18)
Board_0-/TXD: J1.6, U1#2.35 (TXD0/IO1)
Board_0-/ports/ATN: J4#2.11 (ATN), J31#2.11 (ATN), Q5.3 (D), R13#2.2
Board_0-/ports/DAV: J4#2.6 (DAV), J31#2.6 (DAV), Q2.3 (D), R7.2
Board_0-/ports/DIO1: J4#2.1 (DIO1), J31#2.1 (DIO1), U2#2.18 (B1)
Board_0-/ports/DIO2: J4#2.2 (DIO2), J31#2.2 (DIO2), U2#2.17 (B2)
Board_0-/ports/DIO3: J4#2.3 (DIO3), J31#2.3 (DIO3), U2#2.16 (B3)
Board_0-/ports/DIO4: J4#2.4 (DIO4), J31#2.4 (DIO4), U2#2.15 (B4)
Board_0-/ports/DIO5: J4#2.A (DIO5), J31#2.A (DIO5), U2#2.14 (B5)
Board_0-/ports/DIO6: J4#2.B (DIO6), J31#2.B (DIO6), U2#2.13 (B6)
Board_0-/ports/DIO7: J4#2.C (DIO7), J31#2.C (DIO7), U2#2.12 (B7)
Board_0-/ports/DIO8: J4#2.D (DIO8), J31#2.D (DIO8), U2#2.11 (B8)
Board_0-/ports/EOI: J4#2.5 (EOI), J31#2.5 (EOI), Q1#2.3 (D), R4#2.2
Board_0-/ports/IFC: J4#2.9 (IFC), J31#2.9 (IFC)
Board_0-/ports/NDAC: J4#2.8 (NDAC), J31#2.8 (NDAC), Q3.3 (D), R9.2
Board_0-/ports/NRFD: J4#2.7 (NRFD), J31#2.7 (NRFD), Q4.3 (D), R11#2.2
Board_0-/ports/REN: J4#2.E (REN), J31#2.E (REN)
Board_0-/ports/SQR: J4#2.10 (SQR), J31#2.10 (SQR)
Board_0-GND: C1#2.2, C2.2, C3#2.2, D1.1 (K), J1.8, J3.6 (VSS), J3.10 (DET_A), J3.11 (SHIELD), J3.12 (SHIELD), J4#2.12 (GND@12), J4#2.F (GND@F), J4#2.H (GND@H), J4#2.J (GND@J), J4#2.K (GND@K), J4#2.L (GND@L), J4#2.M (GND@M), J4#2.N (GND@N), J31#2.12 (GND@12), J31#2.F (GND@F), J31#2.H (GND@H), J31#2.J (GND@J), J31#2.K (GND@K), J31#2.L (GND@L), J31#2.M (GND@M), J31#2.N (GND@N), U1#2.1 (GND), U1#2.15 (GND), U1#2.38 (GND), U1#2.39 (GND), U2#2.10 (GND), U2#2.19 (~OE), U3#2.1 (GND)
Board_0-Net-(D1-A): D1.2 (A), R3.2
Board_0-VCC: C1#2.1, C3#2.1, J1.2, J3.4 (VDD), Q1#2.1 (G), Q2.1 (G), Q3.1 (G), Q4.1 (G), Q5.1 (G), R1.1, R2.1, R5#2.1, R6#2.1, R8#2.1, R10#2.1, R12.1, U1#2.2 (VDD), U2#2.20 (VCC), U3#2.2 (VO)
Board_1-+5V: C2#2.1, H1#2.1, J1#2.1, R4.1, R7#2.1, R9#2.1, R11.1, R13.1, U3.3 (VI)
Board_1-/BDATA0: U1.8 (IO32), U2.2 (A1)
Board_1-/BDATA1: U1.9 (IO33), U2.3 (A2)
Board_1-/BDATA2: U1.10 (IO25), U2.4 (A3)
Board_1-/BDATA3: U1.11 (IO26), U2.5 (A4)
Board_1-/BDATA4: U1.12 (IO27), U2.6 (A5)
Board_1-/BDATA5: U1.13 (IO14), U2.7 (A6)
Board_1-/BDATA6: U1.14 (IO12), U2.8 (A7)
Board_1-/BDATA7: U1.16 (IO13), U2.9 (A8)
Board_1-/B_ATN: Q5#2.2 (S), R12#2.2, U1.29 (IO5)
Board_1-/B_DAV: Q2#2.2 (S), R6.2, U1.33 (IO21)
Board_1-/B_EOI: Q1.2 (S), R5.2, U1.36 (IO22)
Board_1-/B_NDAC: Q3#2.2 (S), R8.2, U1.27 (IO16)
Board_1-/B_NRFD: Q4#2.2 (S), R10.2, U1.28 (IO17)
Board_1-/CD: J3#2.9 (DET_B), U1.6 (IO34)
Board_1-/CS: J3#2.2 (DAT3/CD), U1.26 (IO4)
Board_1-/DATADIR: U1.23 (IO15), U2.1 (DIR)
Board_1-/EN: J1#2.4, R2#2.2, U1.3 (EN)
Board_1-/IO0: J1#2.3, R1#2.2, U1.25 (IO0)
Board_1-/LED: R3#2.1, U1.24 (IO2)
Board_1-/MISO: J3#2.7 (DAT0), U1.31 (IO19)
Board_1-/MOSI: J3#2.3 (CMD), U1.37 (IO23)
Board_1-/RXD: J1#2.5, U1.34 (RXD0/IO3)
Board_1-/SCK: J3#2.5 (CLK), U1.30 (IO18)
Board_1-/TXD: J1#2.6, U1.35 (TXD0/IO1)
Board_1-/ports/ATN: J4.11 (ATN), J31.11 (ATN), Q5#2.3 (D), R13.2
Board_1-/ports/DAV: J4.6 (DAV), J31.6 (DAV), Q2#2.3 (D), R7#2.2
Board_1-/ports/DIO1: J4.1 (DIO1), J31.1 (DIO1), U2.18 (B1)
Board_1-/ports/DIO2: J4.2 (DIO2), J31.2 (DIO2), U2.17 (B2)
Board_1-/ports/DIO3: J4.3 (DIO3), J31.3 (DIO3), U2.16 (B3)
Board_1-/ports/DIO4: J4.4 (DIO4), J31.4 (DIO4), U2.15 (B4)
Board_1-/ports/DIO5: J4.A (DIO5), J31.A (DIO5), U2.14 (B5)
Board_1-/ports/DIO6: J4.B (DIO6), J31.B (DIO6), U2.13 (B6)
Board_1-/ports/DIO7: J4.C (DIO7), J31.C (DIO7), U2.12 (B7)
Board_1-/ports/DIO8: J4.D (DIO8), J31.D (DIO8), U2.11 (B8)
Board_1-/ports/EOI: J4.5 (EOI), J31.5 (EOI), Q1.3 (D), R4.2
Board_1-/ports/IFC: J4.9 (IFC), J31.9 (IFC)
Board_1-/ports/NDAC: J4.8 (NDAC), J31.8 (NDAC), Q3#2.3 (D), R9#2.2
Board_1-/ports/NRFD: J4.7 (NRFD), J31.7 (NRFD), Q4#2.3 (D), R11.2
Board_1-/ports/REN: J4.E (REN), J31.E (REN)
Board_1-/ports/SQR: J4.10 (SQR), J31.10 (SQR)
Board_1-GND: C1.2, C2#2.2, C3.2, D1#2.1 (K), J1#2.8, J3#2.6 (VSS), J3#2.10 (DET_A), J3#2.11 (SHIELD), J3#2.12 (SHIELD), J4.12 (GND@12), J4.F (GND@F), J4.H (GND@H), J4.J (GND@J), J4.K (GND@K), J4.L (GND@L), J4.M (GND@M), J4.N (GND@N), J31.12 (GND@12), J31.F (GND@F), J31.H (GND@H), J31.J (GND@J), J31.K (GND@K), J31.L (GND@L), J31.M (GND@M), J31.N (GND@N), U1.1 (GND), U1.15 (GND), U1.38 (GND), U1.39 (GND), U2.10 (GND), U2.19 (~OE), U3.1 (GND)
Board_1-Net-(D1-A): D1#2.2 (A), R3#2.2
Board_1-VCC: C1.1, C3.1, J1#2.2, J3#2.4 (VDD), Q1.1 (G), Q2#2.1 (G), Q3#2.1 (G), Q4#2.1 (G), Q5#2.1 (G), R1#2.1, R2#2.1, R5.1, R6.1, R8.1, R10.1, R12#2.1, U1.2 (VDD), U2.20 (VCC), U3.2 (VO)

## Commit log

2025-06-27 JLCPCD order
    [2xpetdisk esp32.kicad_pcb, BOM_JLCSMT.xlsx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]
2025-06-27 Added readme, images, pdf, gerber (zip).
    [2xpetdisk esp32.kicad_pcb, petdisk esp32.kicad_pcb]
2025-06-28 Files ordered from JLCPCB.
    connector silkscreen fix
    [2xpetdisk esp32.kicad_pcb, petdisk esp32.kicad_pcb]
2025-06-28 Update README with warning that board is still untested
2025-07-16 Small touchup
    [2xpetdisk esp32.kicad_pcb]
2025-08-13 3D printed case based on YAPP
    openscad
    [Yapp_petdisk_cbm.scad, Yapp_petdisk_cbm.stl]

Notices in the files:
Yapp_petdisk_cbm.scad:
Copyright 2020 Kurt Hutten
